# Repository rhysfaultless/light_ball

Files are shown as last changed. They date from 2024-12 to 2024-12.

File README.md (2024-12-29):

# light_ball

<br/>

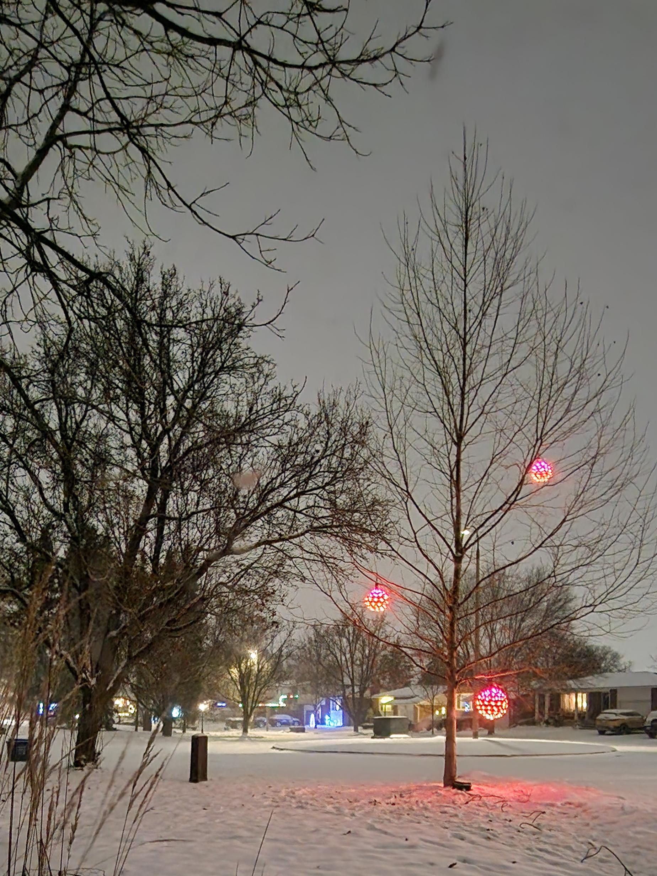
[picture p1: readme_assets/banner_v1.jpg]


## Background

Christmas lights on trees are beautiful, but the light strings are difficult to install.
It is possible to install lights in conifer trees using a ladder and pole.

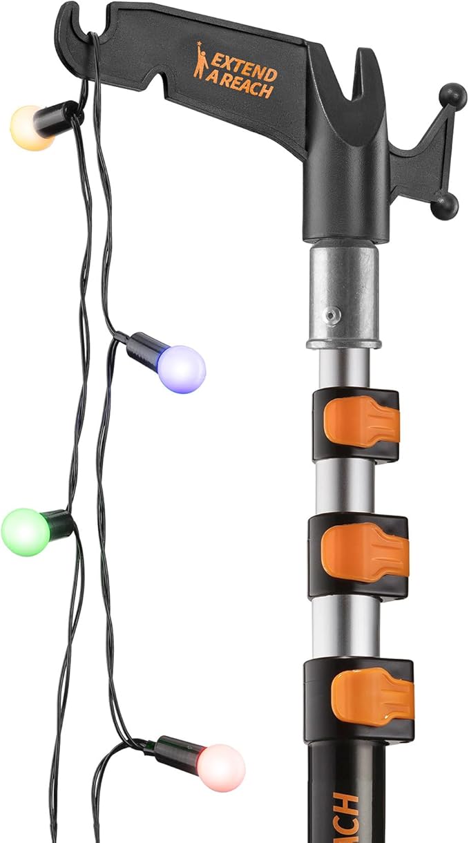
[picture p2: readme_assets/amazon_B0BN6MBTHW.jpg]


Example, _[Amazon B0BN6MBTHW](https://www.amazon.ca/Telescopic-Telescoping-Installation-Birdfeeders-Lightweight/dp/B0BN6MBTHW)_

This works when the tree is less than 10 metres tall _(35 feet)_, noting that it is difficult to remove the lights. 
Taller trees and deciduous trees require a boom-lift, due to the tree's height and limited access between branches.

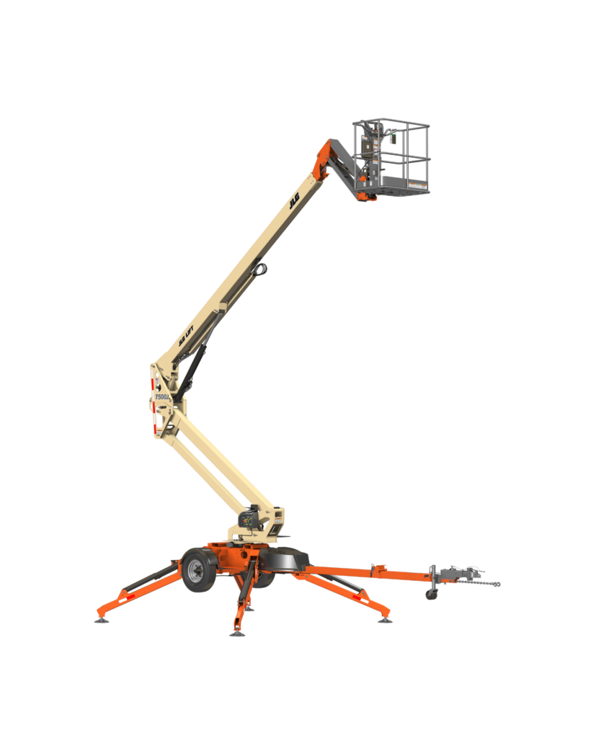
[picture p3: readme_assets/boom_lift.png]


Home Depot rents these boom-lifts:

| Height | Height  | Rental cost, per day _(Canadian dollars, 2024)_ |
| :---: | :-----: | :---: |
| 10 metres | 35 feet | $370 |
| 15 metres | 50 feet | $490 |

It's a significant investment; especially if you plan to remove the lights after the season, or when you consider the maintenance task of replacing lights that burn out.

### Background, Light Options To Consider

| Light Option | Image | Notes |
| :---: | :---: | :---: |
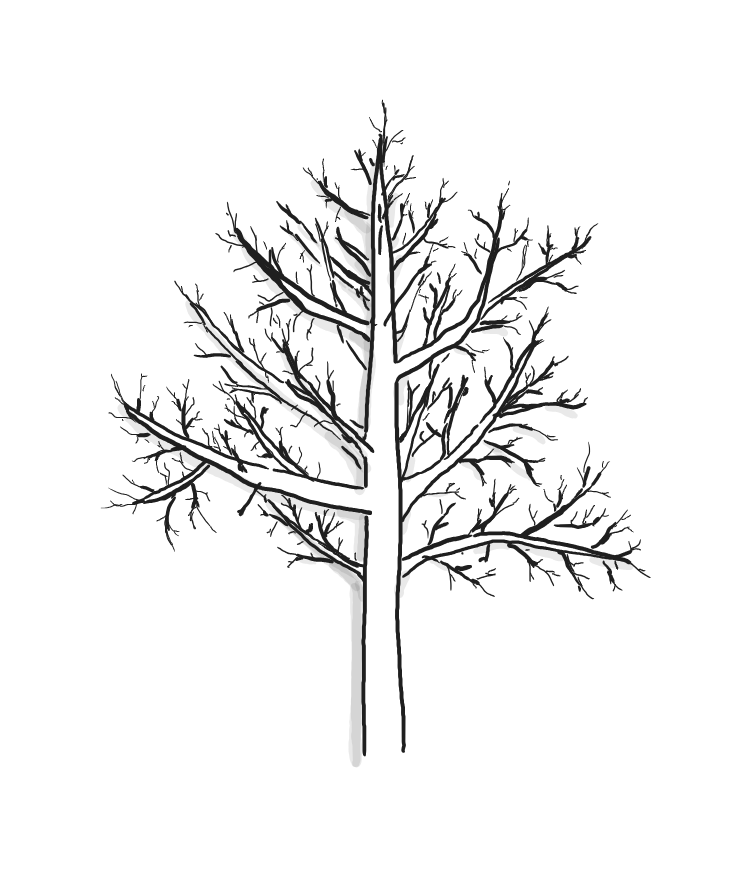
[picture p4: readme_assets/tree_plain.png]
| None |  | |
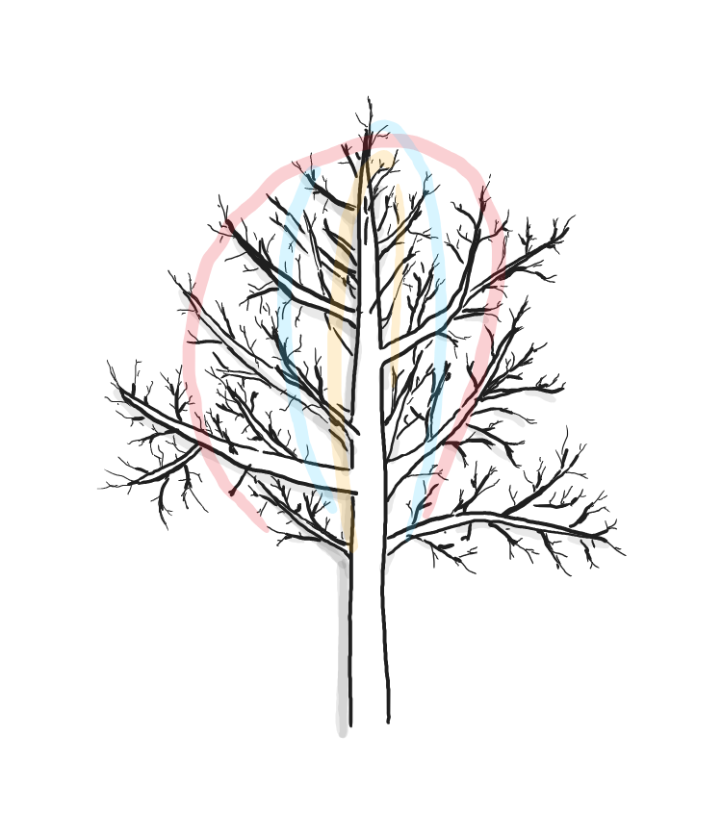
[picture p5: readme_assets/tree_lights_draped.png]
| Draped |  | String lights draped over the tree's canopy. This does not look good. |
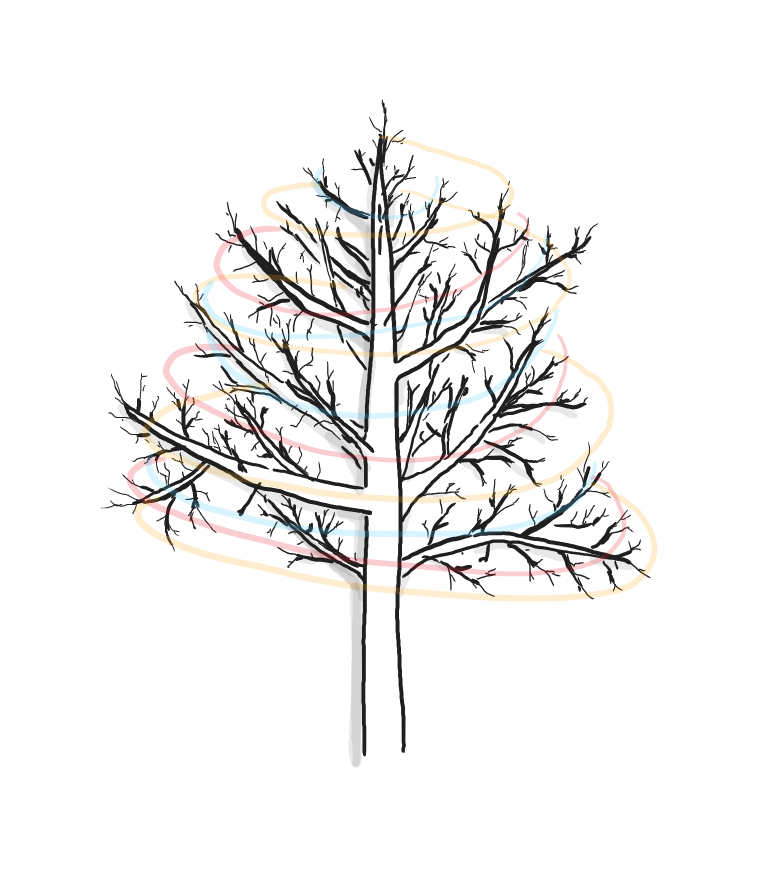
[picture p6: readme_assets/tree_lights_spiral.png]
| Spiral |  | String lights wrapped around the tree's canopy. This looks good, but takes a long time to install. |
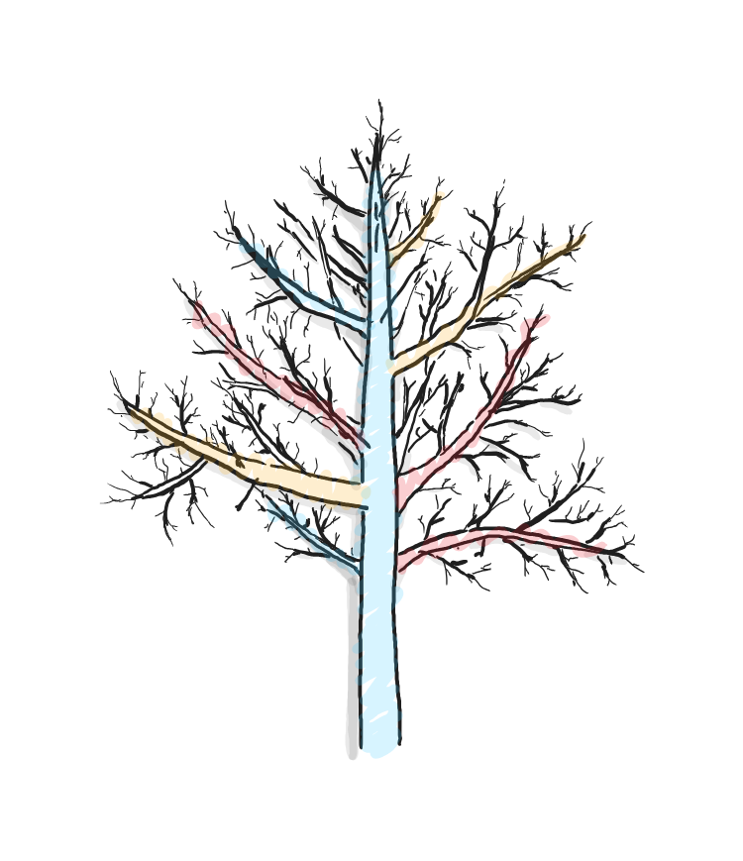
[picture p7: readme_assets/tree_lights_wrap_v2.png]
| Wrap |   | String lights wrapped around the tree's trunk and branches. This looks good, but takes a long time to install. |
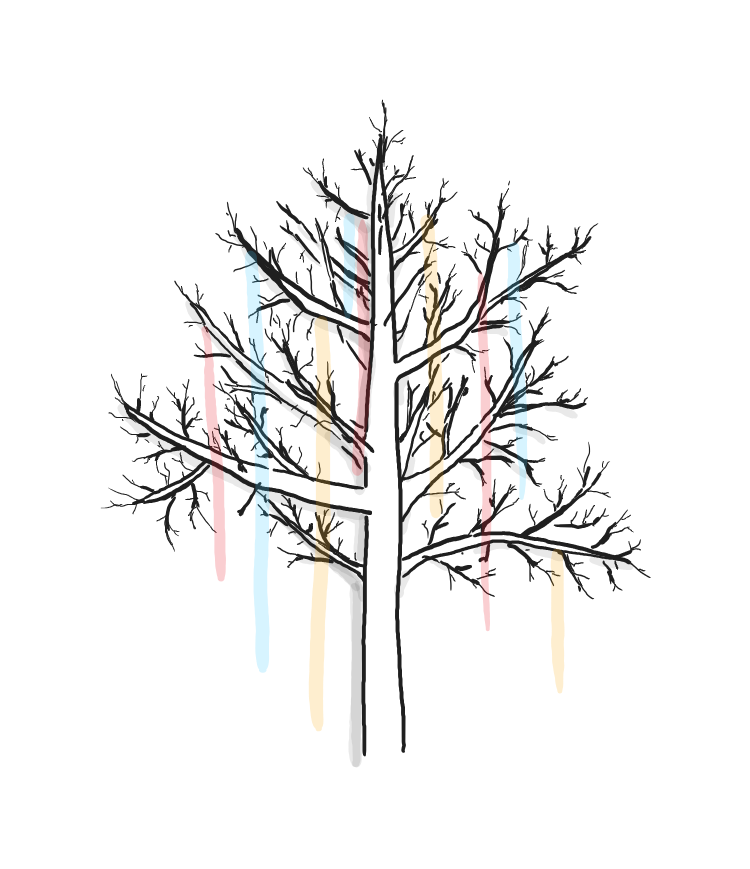
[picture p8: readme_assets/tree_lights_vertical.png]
| Vertical |  | String lights hanging from tree branches, similar to a weeping willow's hanging branches. |
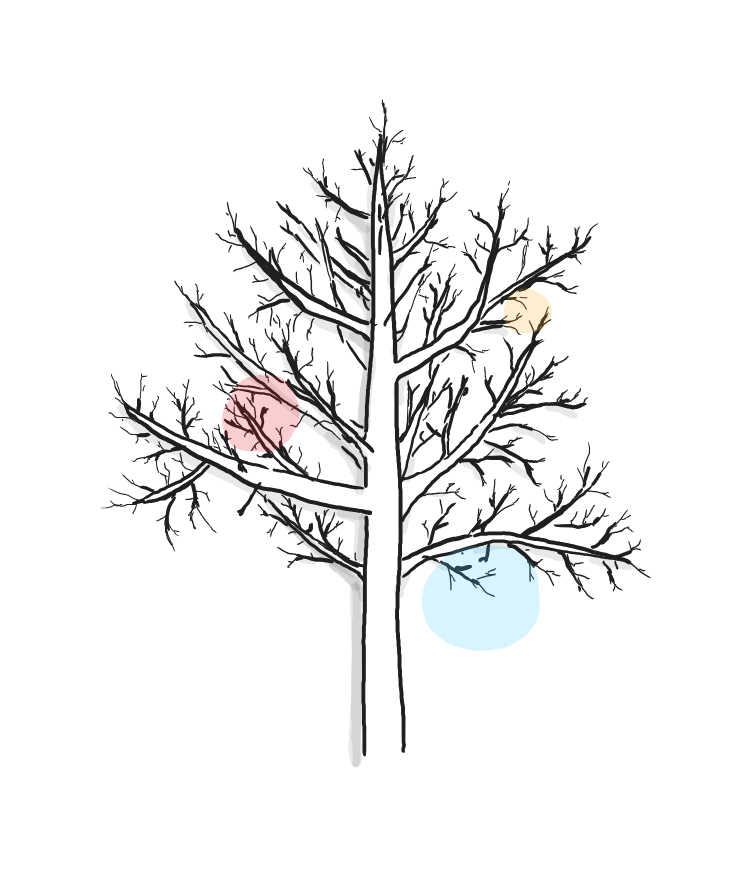
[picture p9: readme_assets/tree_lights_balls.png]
| Balls |  | There are consumer options available, with single colours, and up to 300 mm diameter. There are larger options, but they are intended for use on the ground since they are heavy or have high wind resistance. |
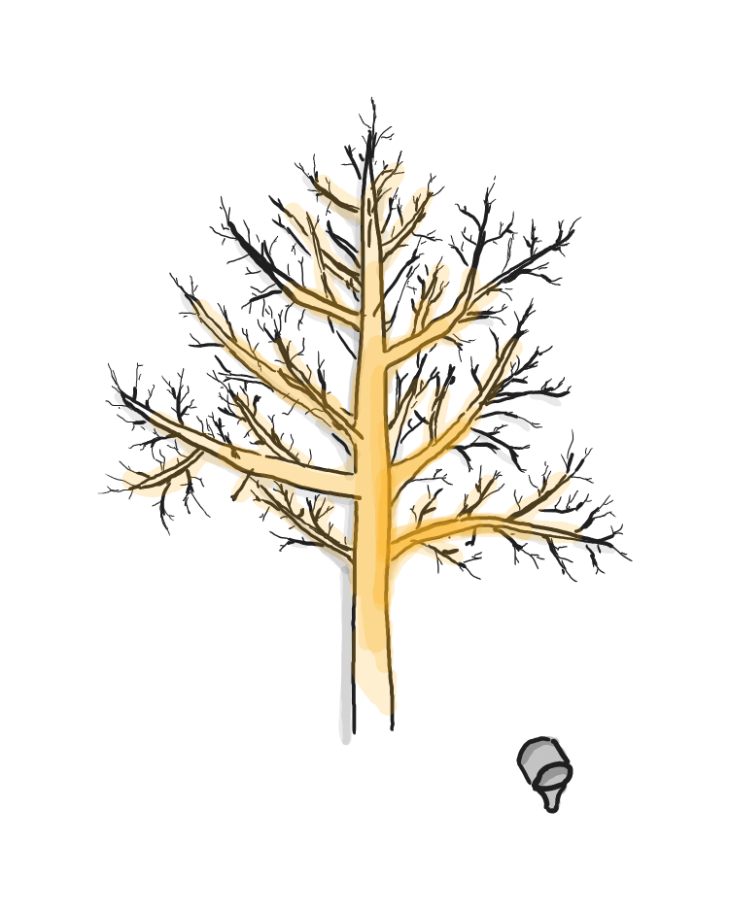
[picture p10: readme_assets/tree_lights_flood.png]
| Flood |  | Inexpensive light at the base of the tree. Typically floods the tree with a single colour of light, with minimal range. It can get covered from snowfall. |
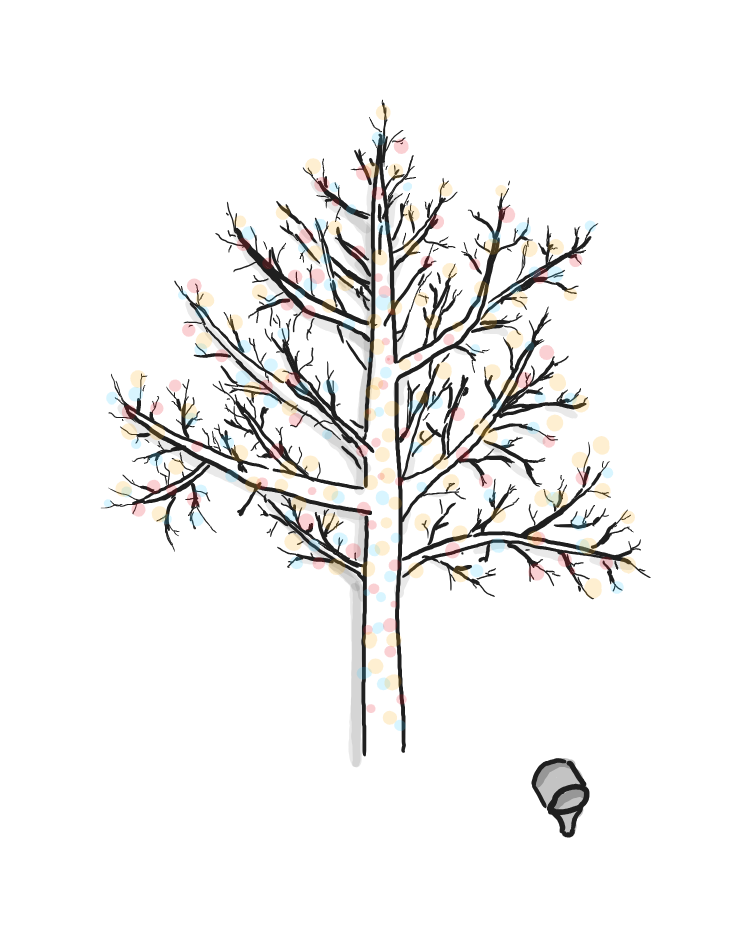
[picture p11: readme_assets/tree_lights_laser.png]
| Laser |  | Inexpensive light at the base of the tree. It makes many small dots on the tree, but also has a long overshoot onto surfaces behind the tree. It can get covered from snowfall. |

### Background, Power Sources For Lights

* AC mains power, as how most North American christmas lights are powered.
* Low voltage DC cable run up the tree. 12 VDC custom outdoor wiring does not require inspection from Electrical Safety Authority in Ontario Canada. 
* Wireless power transimission, such as Disney's: _[Wireless Power Transmission Safely Charges Devices Anywhere Within A Room](https://la.disneyresearch.com/innovations/wireless-power-room/)_.
* Solar panels on the lights, with a battery.
* PoE _Power Over Ethernet_. The passive option uses 24 VDC, the active options use 48 - 52 VDC.

### Background, Installation Methods To Consider

1. Ladder and pole.
2. Pole with a hook.
3. Pole with a catch release.
4. Climbing trees.
5. Drone with a catch release
6. Lights installed onto a drone. The drone would remain in the tree.
7. Pulleys installed into trees, which then allow the lights to be raised and lowered. This is similar to a flag pole.

### Background, Design Requirements

1. Colours and white available _(preferably user selectable after installation)_
2. Lights visible at dusk.
3. DC low voltage, or existing approved device.
4. IP54 minimum, to allow for rain and snow melt.
5. Approved FCC or Industry Canada components to not cause RF issues. This is only relevant if the devices include Wi-Fi, Bluetooth, Zigbee, or similar radio communication.

### Background, Design Intent

There is an unmet design space for Light Balls and Vertical Strands that can be installed in tall trees.
It is uncommon to see Spiral or Wrapped string lights on tall trees due to the installation cost.
People sometimes add Flood or Laser lights, but the light concentrates near the base of the tree.
The goal is to design a light source that:

1. Can be installed in a large tree using methods such as a ladder-and-pole, a boom-lift, or using a drone _(preferred option)_. 
2. Can be powered from this location. Any safe power method is acceptable, but it should consider installation difficulty, maintenance burden, and reliability.

## Concept 2024-12

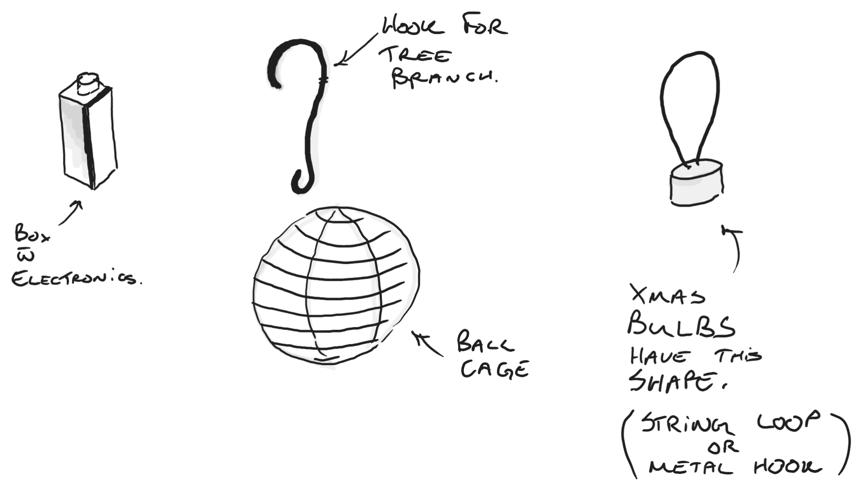
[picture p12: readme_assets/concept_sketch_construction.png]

<br/>
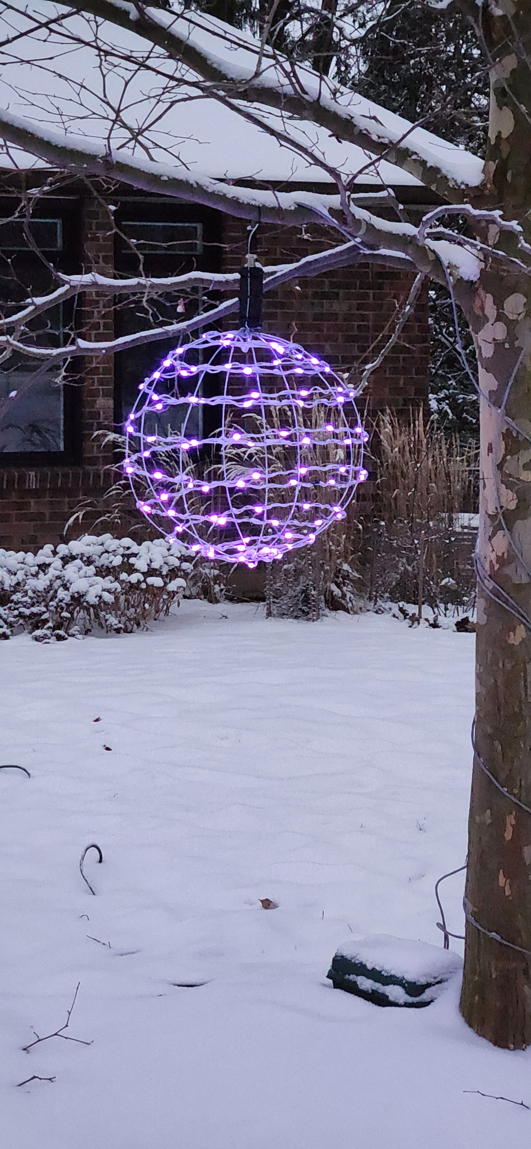
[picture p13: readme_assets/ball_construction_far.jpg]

<br/>
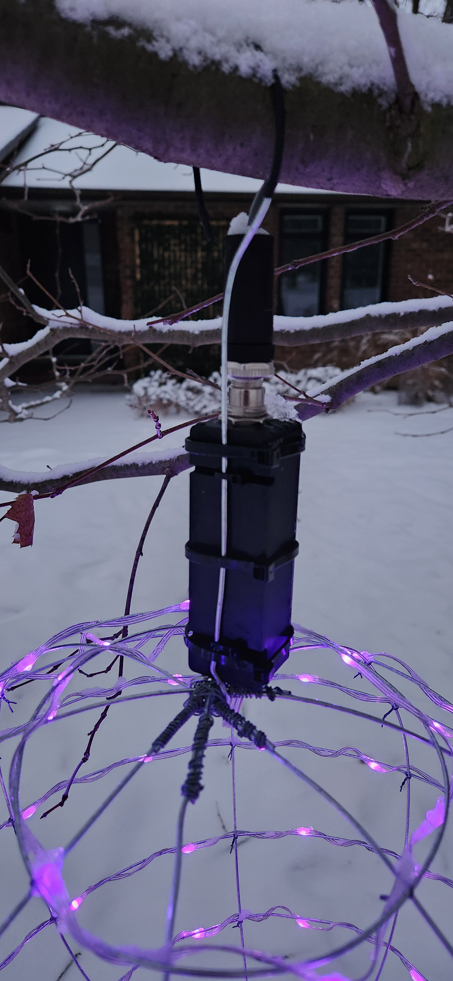
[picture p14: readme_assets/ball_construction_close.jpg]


### Concept 2024-12, Parts List

| Subsection | Description | Vendor | Item |
| :--- | :--- | :--- | :--- |
| | | | |
| Frame | 14 AWG galvanized steel wire _(Ø2 mm)_ | Home Depot | 1001028009 |
| Frame | 24 AWG galvanized steel wire _(Ø0.6 mm)_ | Home Depot | 1001027858 |
| Frame | Cyanoacrylate | Loctite | 401 |
| | | | |
| Electronics  | ESP32 microcontroller | Amazon | B0D8T7Z1P5 |
| Electronics  | DC-DC buck converter | Amazon | B07V4RT4H8 |
| Electronics  | Light Strands, WS2812B | Amazon | B0CD1YBFPX |
| Electronics  | Solder | | |
| Electronics  | Flux for soldering | | |
| Electronics  | Hook-Up-Wire, 20 AWG, Red | | |
| Electronics  | Hook-Up-Wire, 20 AWG, Black | | |
| Electronics  | Hook-Up-Wire, 20 AWG, Yellow | | |
| Electronics  | Fuse 3 A | Digikey | F2583CT-ND |
| Electronics  | M12 bulkhead connector, 5-position, female | Digikey | A126843-ND |
| Electonics | Enclosure body | Custom | [enclosure_body.stl](./enclosure_files/enclosure_body.stl) |
| Electronics  | Enclosure lid | Custom | [enclosure_lid.stl](./enclosure_files/enclosure_lid.stl) |
| Electronics  | Cable ties | | | 
| Electonics | 3M VHB, double sided foam tape | | |
| Electronics  | Heat shrink tubing | | |
| | | | |
| Power Supply | Power supply, 110 VAC to 12 VDC, 5 A | | _recovered from e-waste_ | 
| Power Supply | Fuse, ATO, 3 A | Digikey | F4193-ND |
| Power Supply | Fuse holder | Digikey | FHAC0001ZXJA-ND |
| Power Supply | Terminal block, 6-position, Red | Digikey | 277-15998-ND |
| Power Supply | Terminal block, 6-position, Black | Digikey | 277-15783-ND |
| Power Supply | Terminal block, 6-position, Brown | Digikey | 277-18255-ND |
| Power Supply | Cable, 2X 20 AWG | | |
| Power Supply | M12 inline connector, 5-position, male | Digikey | A133885-ND |
| Power Supply | Waterproof box | Canadian Tire | EF-B02 |
| Power Supply | AC extension cable | | |
| | | | |
| Network | 2.4 GHz access point / router | | |

### Concept 2024-12, Tools

* Frame
  * Needle nose plyers
  * Wire shears
  * Measuring tape
* Electronics
  * Wire strippers
  * Soldering iron
  * USB-C cable and computer _(for firmware installation)_
  * 3D printer
  * Adjustable wrench _(for M12 body)_
  * Heat gun _(for heat shrink tubing)_
  * Multimeter _(for configuring the DC-DC buck converter's output voltage)_
* Power Supply
  * Wire strippers
  * Small flat screwdriver _(for terminal block clamps, and M12 connector screws)_
  * Adjustable wrench _(for M12 body)_

### Concept 2024-12, Frame

The ball has 3 vertical metal hoops, and a spiral of metal wire around the hoops.
These main structural pieces use galvanized 14 gauge steel wire _(Ø2 mm)_.
The structural pieces are tied together using short sections of galvanized 24 gauge steel wire _(Ø0.6 mm)_.
These tied joints are then coated with cyanoacrylate _(Super Glue)_.
I then added a hook to the ball, using the same 14 gauge wire.
There is a section of rubber heat-shrink-tube on the hook, to minimize abrasion to the tree's bark.

I made three sizes of spheres:

* Ø400 mm _(Ø16 inch)_
* Ø300 mm _(Ø12 inch)_
* Ø230 mm _(Ø9 inch)_

I used a steel frame to reduce weight and cros-sectional area for wind resistance.
I referenced grapevine balls when designing the frame.

_Notes:_ 
* _The hook should use thicker material in future iterations, as it was prone to bending during installation in the tree._ 
* _It took a long time to make these balls. Consider using a 3D printed ball, or developing tooling to tie to metal hoops together._

### Concept 2024-12, Electronics Soldering

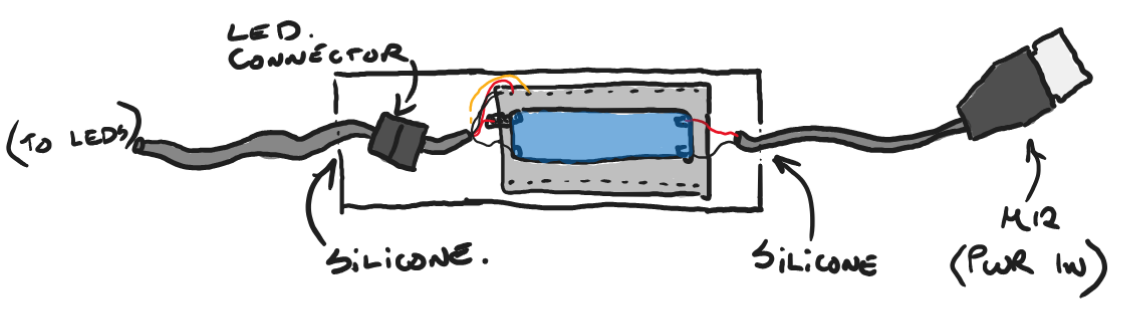
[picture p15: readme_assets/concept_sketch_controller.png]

<br/>
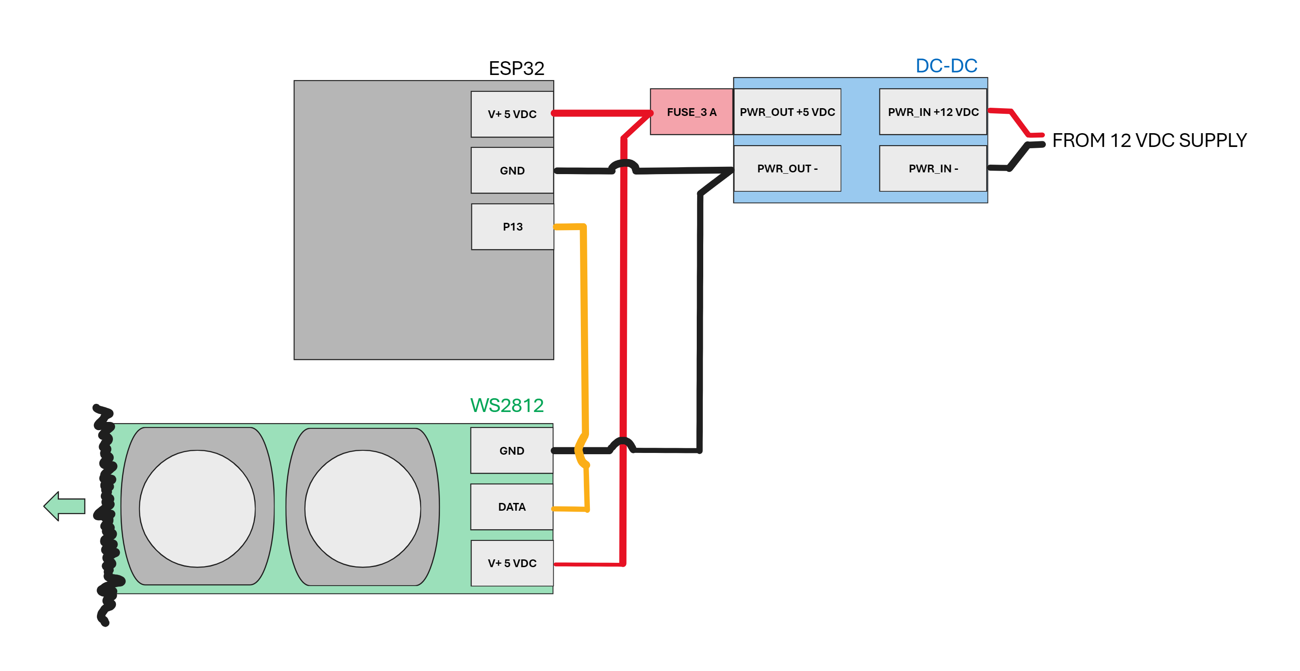
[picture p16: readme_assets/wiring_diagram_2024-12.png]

<br/>

The wiring diagram above shows the electronics for the Light Ball.
I soldered these components together.

_Note that I did not include a level converter for the light's data line._
_The ESP32 outputs 3.3 V on its D13 line, but the lights suggest an input signal of 5 V._
_I did not include a level converter, since my lighting test results seemed acceptable, without unintended colours of flickering._

### Concept 2024-12, Electronics Firmware And Configuration

With the electronics soldered, I then connected the ESP32 development board to my computer with a USB cable.
I went to [install.wled.me](https://install.wled.me/), selected firmware version 0.14.4, and then clicked install.
In the pop-up window, I selected the relevant computer port.

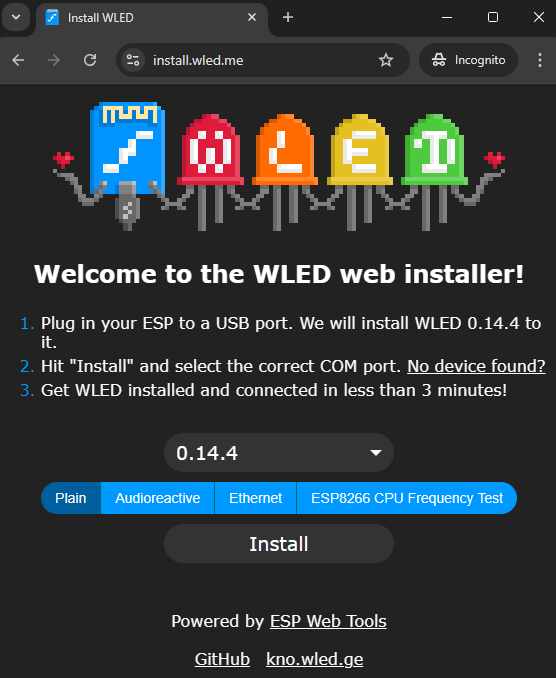
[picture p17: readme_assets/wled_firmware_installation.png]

<br/>
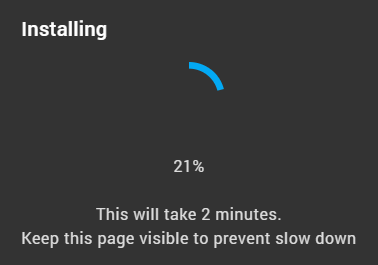
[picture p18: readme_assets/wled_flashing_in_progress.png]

<br/>
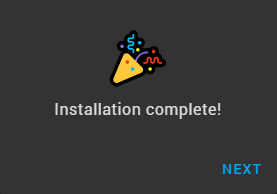
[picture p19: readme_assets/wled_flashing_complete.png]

<br/>

After installing the firmware, the WLED installer will ask you to enter Wi-Fi network details.

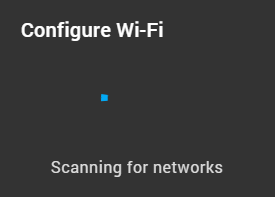
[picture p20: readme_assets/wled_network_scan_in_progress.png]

<br/>
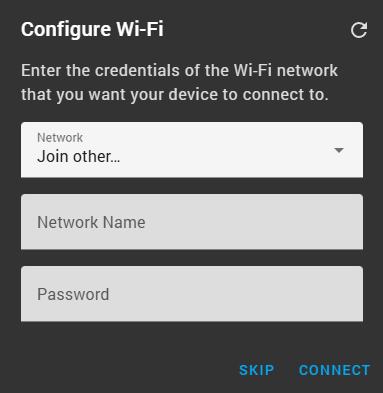
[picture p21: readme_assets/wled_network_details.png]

<br/>
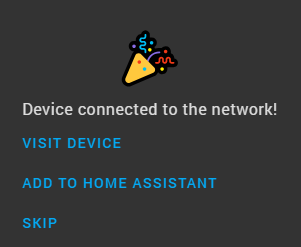
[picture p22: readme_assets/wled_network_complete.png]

<br/>

You can click _Visit Device_, which will navigate to the ESP32's webpage.
_Note: I had to first switch my computer to a new Wi-Fi SSID, since I am using a separate LAN network without internet access to simplify security._

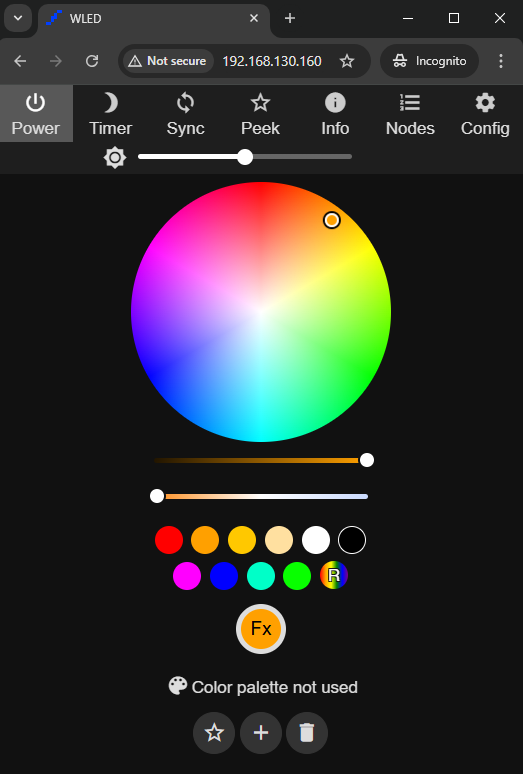
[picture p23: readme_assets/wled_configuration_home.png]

<br/>

_The browser's URL is a dyanmic address that my router assigned._
_I will change this to a Static IP in a later section of this readme._

Next, I clicked the gear in the top right corner to configure:

* LED Preferences
  * GPIO as pin D13
  * Length as the number of WS2812 LEDs in the string

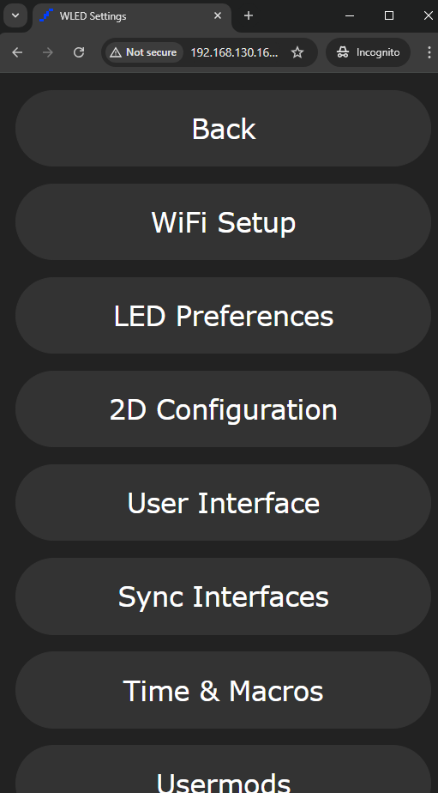
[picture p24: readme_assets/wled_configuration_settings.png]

<br/>
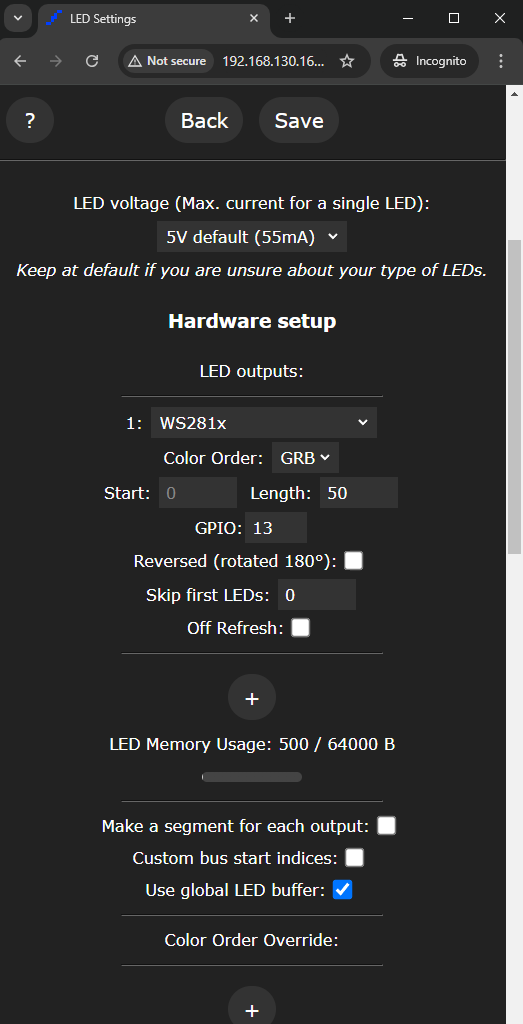
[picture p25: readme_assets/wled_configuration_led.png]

<br/>

* Sync
  * The primary ESP32 ball as the Leader
  * Other ESP32 light balls as the Followers
  * _Sync will have all the light balls follow the same light patterns_

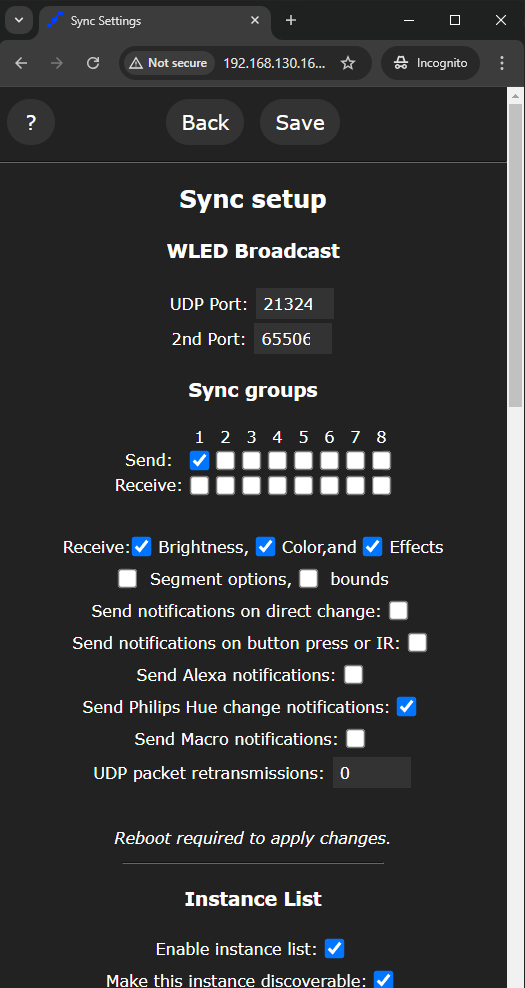
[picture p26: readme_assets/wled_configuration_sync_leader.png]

<br/>
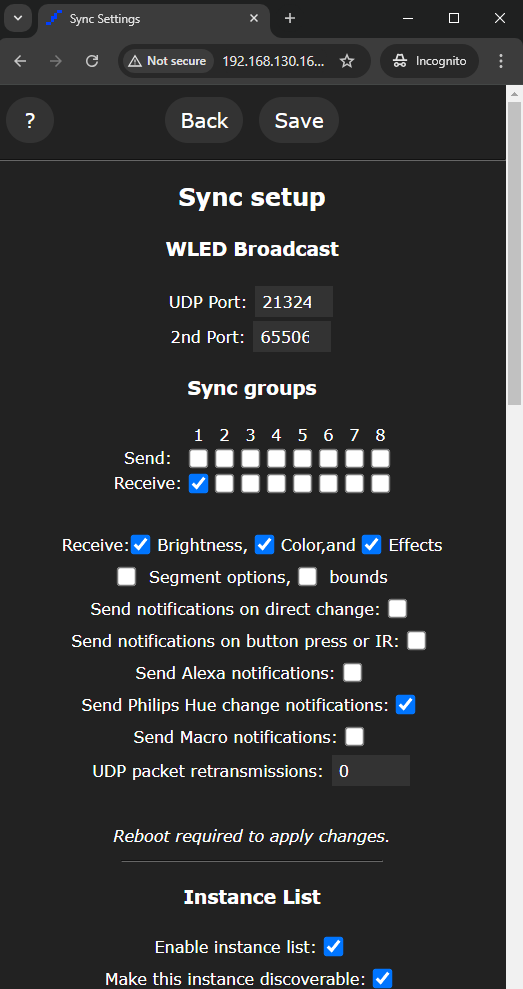
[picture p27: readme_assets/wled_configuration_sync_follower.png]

<br/>

* Time & Macros
  * _Setting times when the lights change patterns._
  * _This is only required on the Leader._
  * _Followers should also have the OFF settings, in case they lose Wi-Fi connection._
  * _Preset 0 is set to black, to shut the lights off._
  * _Preset 1 is set the colour pattern I want to use._
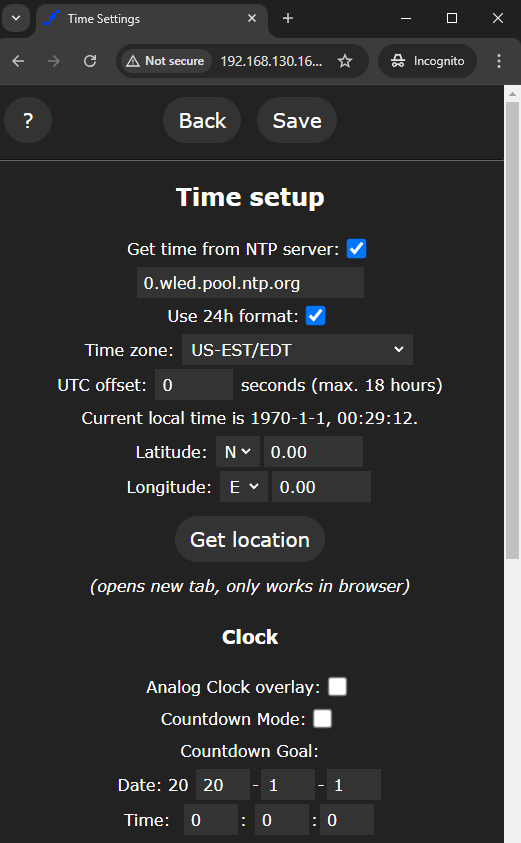
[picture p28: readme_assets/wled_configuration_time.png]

<br/>
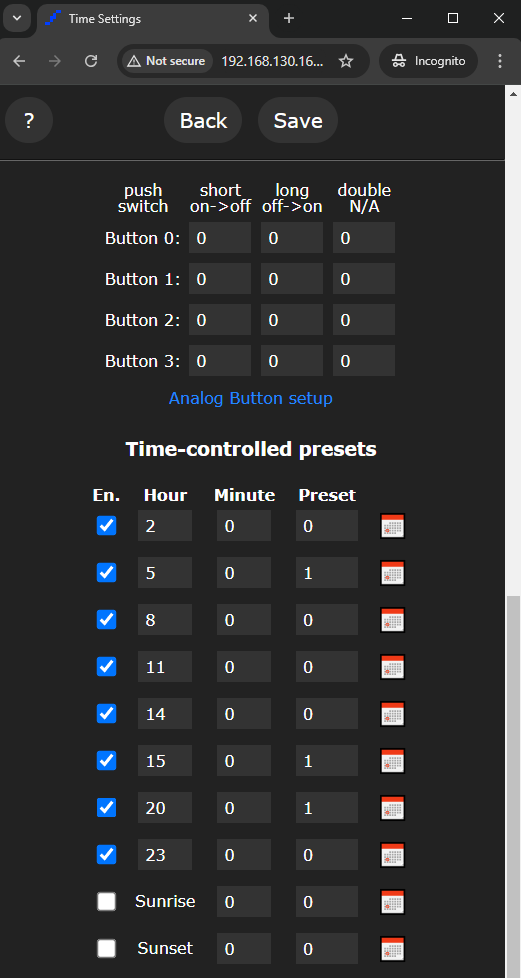
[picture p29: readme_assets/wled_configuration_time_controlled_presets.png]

<br/>

### Concept 2024-12, Electronics Installation

The electronics were placed into the custom enclosure, and then sealed inside with cyanoacrylate glue.
Take note of the ESP32's antenna location, as you will need to point it towards the access point _(described later, in the Network section)_.

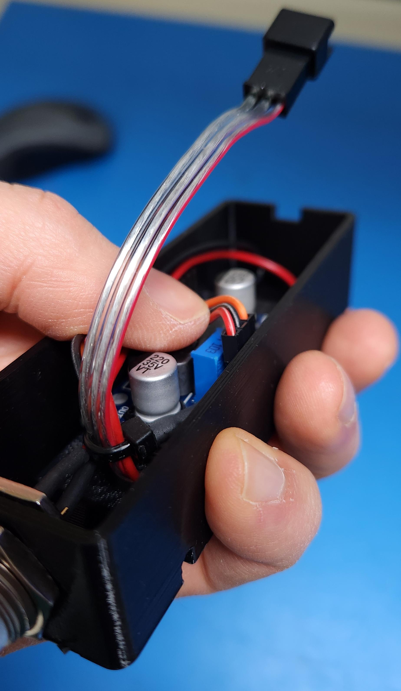
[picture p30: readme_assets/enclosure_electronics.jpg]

<br/>

I then used cable ties to attach the enclosure to the ball's hook.
I considered placing the enclosure inside the ball, but was concerned the ball's structure would act as a Faraday cage, blocking the Wi-Fi 2.4 GHz radio.
Further testing or changing to a plastic ball structure could make this integration tidier, without the radio frequency concern.

### Concept 2024-12, Power Supply

I placed a AC-DC converter in a waterproof box, fused the output, and then used terminal blocks to distribute power to the three light balls.
The AC source has a GFCI outlet.

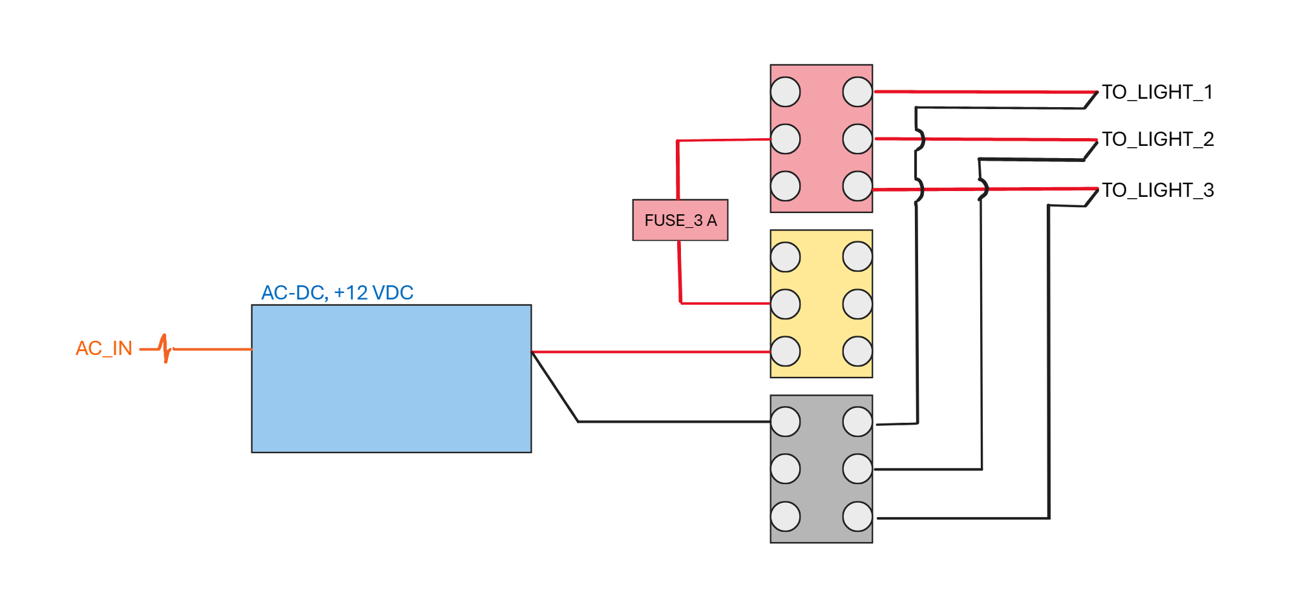
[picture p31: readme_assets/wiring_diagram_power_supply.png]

<br/>

### Concept 2024-12, Network

I configured the 2.4 GHz access point + router so the three ESP32 microcontrollers have static IPs.
This simplifies troubleshooting, as I can tell which controllers have network issues, without having to remember MAC addressess.

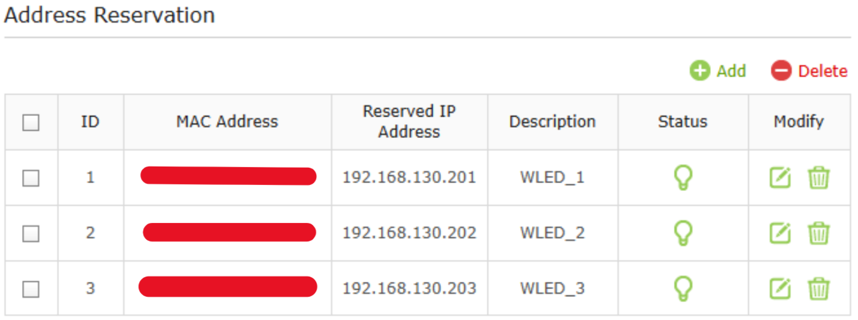
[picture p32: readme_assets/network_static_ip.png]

<br/>

I also changed the router's dynamic DHCP address range, to make sure it does not assign another device one of these static IPs.
The network will have devices with dynamic IPs, as I intend to control the lights using a phone over LAN.

### Concept 2024-12, Thoughts About The Concept

* Observations:
  * It was slow / difficult to make the balls' frames.
  * The controller's enclosure was large, and more visible than expected.
  * Size of the ball seemed acceptable.
  * OTS controller, or a premade PCBA would be preferable.
  * The ESP32 development board's Wi-Fi signal strength was low, and would sometimes drop off when an ICE car was near the tree.
  * The +12 VDC power cable running up the tree will complicate installation in tall trees.
* Next steps / to consider:
  * Create a PCBA for the ESP32, DC-DC, and fusing.
  * Test a solar powered option, which charges a battery.
  * Could design the ball's frame for installation with a drone, if methods for retreival are considered.
  * Change the ball's frame to plastic, to simplify build, and improve Wi-Fi.
  * Look into ESP32 mesh network, or bridge repeater settings.

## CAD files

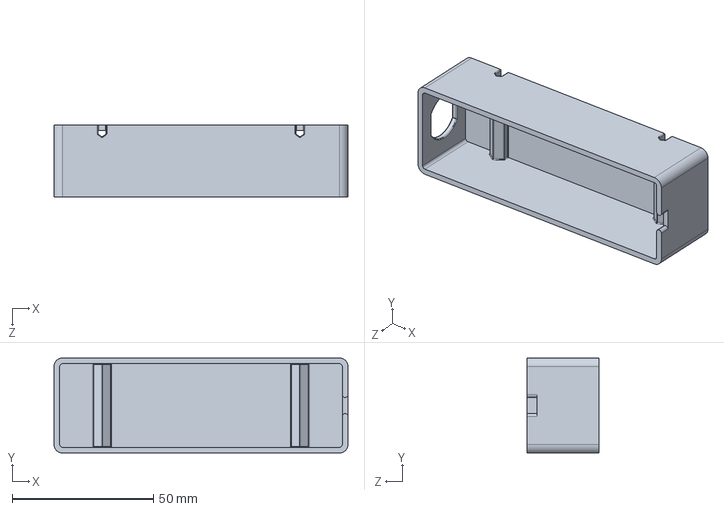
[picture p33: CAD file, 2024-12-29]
enclosure_files/enclosure_body.step
104.0 x 33.6 x 25.5 mm

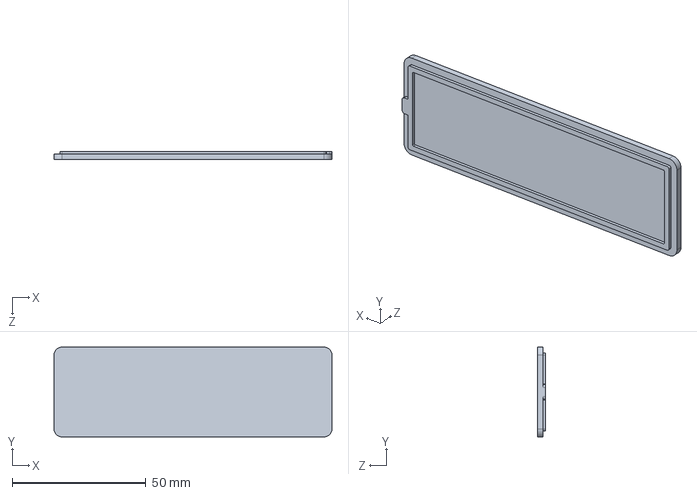
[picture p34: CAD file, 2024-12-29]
enclosure_files/enclosure_lid.step
104.0 x 33.6 x 3.00 mm

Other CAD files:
enclosure_files/enclosure_body.stl
enclosure_files/enclosure_lid.stl
